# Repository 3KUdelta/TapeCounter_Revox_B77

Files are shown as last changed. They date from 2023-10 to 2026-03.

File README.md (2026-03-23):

# TapeCounter_Revox_B77
Arduino Nano based, digital counter for a Revox B77 Reel-to-Reel with Rewind2Zero function.

# PLEASE SEE NEW VERSION - allthough this version is perfectly running, it will not be further managed or developed. https://github.com/3KUdelta/TapeCounter_Revox_B77_NG

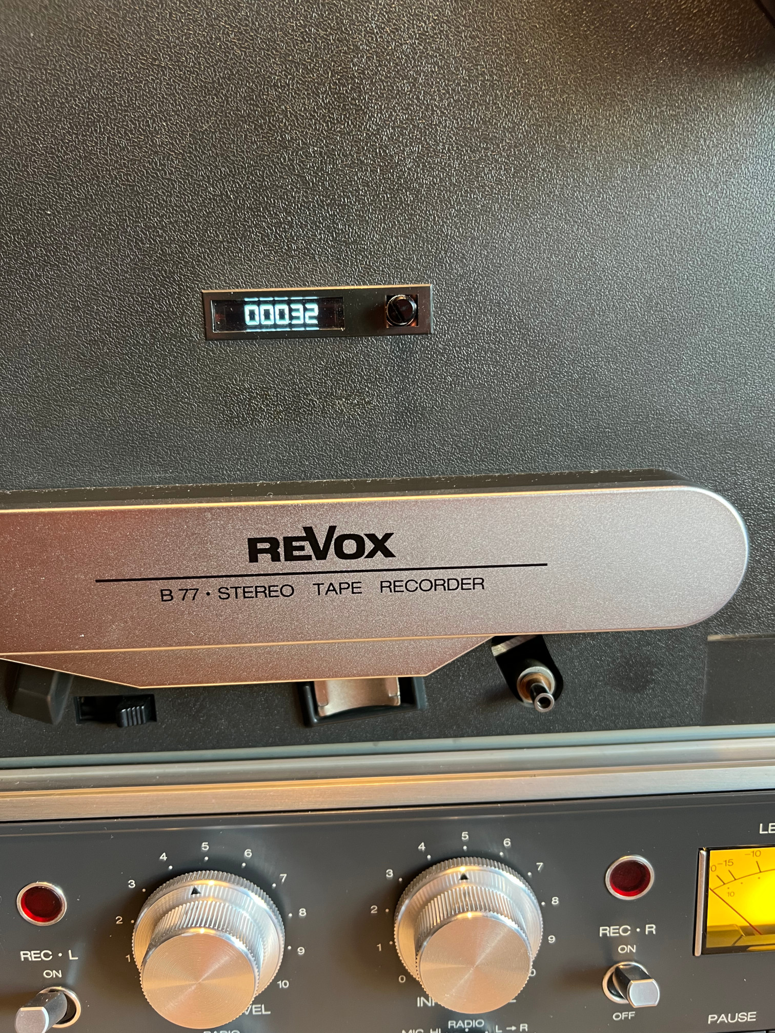
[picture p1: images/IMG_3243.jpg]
(https://github.com/3KUdelta/TapeCounter_Revox_B77)


Original idea & code from https://old-fidelity-forum.de/thread-38940.html
Special thanks to DIYLAB-Bruno, User "Gogosch" and all that have participated - excellent work, Gentlemen!

Version 2.0 stable:

- Click on boot: total running hours
- Click to reset
- Turn to change from counter to meters to seconds (simple conversion - no true seconds)
- Hold to change brightness
- Pause indicator (needs Pause Memory PCB: eBay Mauro200id)
- Auto rewind to 0 on double click (needs relais module)
- 3D files for relais bracket, main board distance bracket and IR Sensor clips are included

Hardware needed:

- 2 HW-006 V1.3 Line Tracker Sensor Modules
- 4 white markers on right spooling motor
- 1 EC12 RE1 360 Degree Rotary Encocer with push button
- 1 0.91 inch OLED module white 128X32
- ~~1 Mini DC-DC 12-24V To 5V 3A Step Down Power Supply Module~~ (edit: unfortunately this causes a very low disturbing noise)
- 1 Mini 230V AC to 5V DC 2A power supply (to get clean discrete power for your arduino & acessories)
- 1 Relay module 2 Channel 5V 12V Relay Module Board Shield with Optocoupler Support High and Low Level Trigger for Arduino 

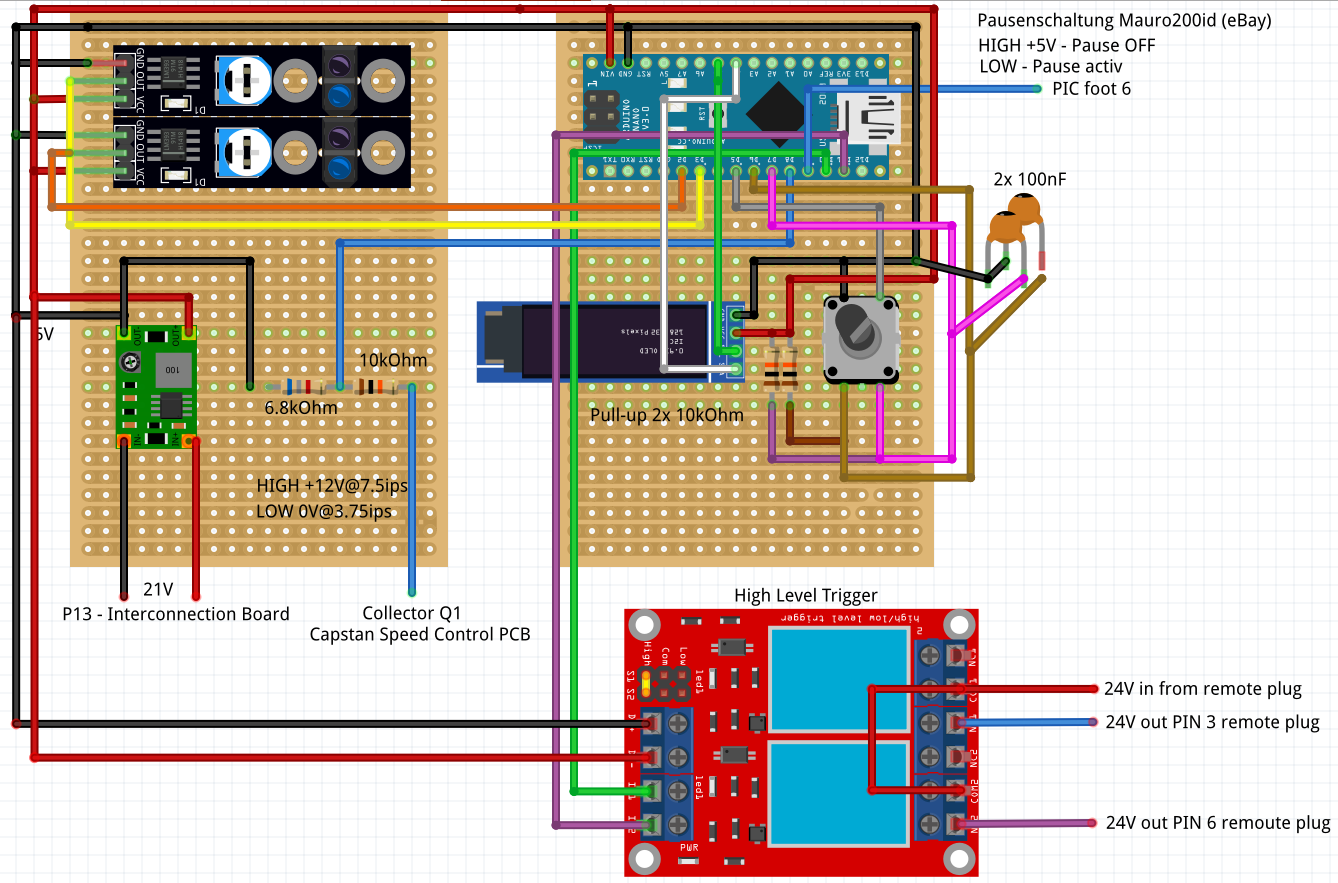
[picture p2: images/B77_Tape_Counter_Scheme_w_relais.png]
(https://github.com/3KUdelta/TapeCounter_Revox_B77)


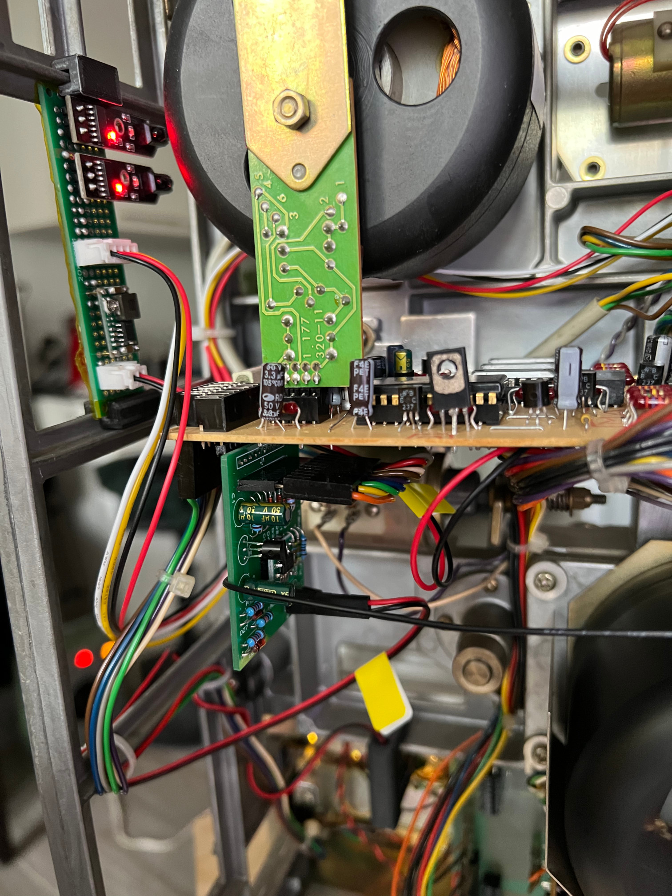
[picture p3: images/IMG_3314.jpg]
(https://github.com/3KUdelta/TapeCounter_Revox_B77)


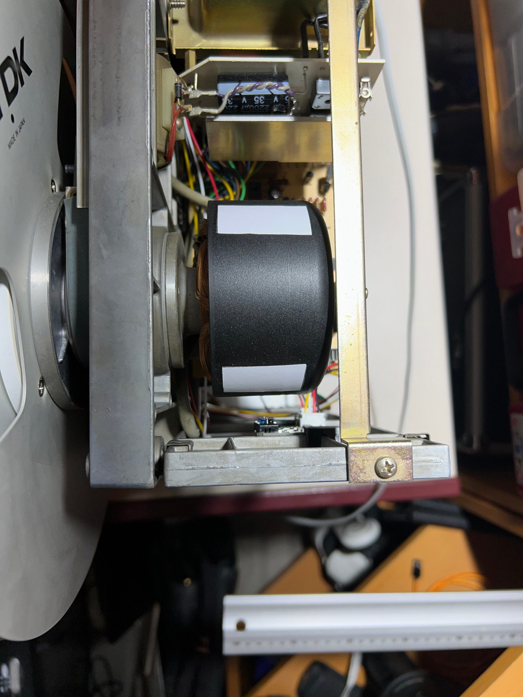
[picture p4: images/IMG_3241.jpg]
(https://github.com/3KUdelta/TapeCounter_Revox_B77)


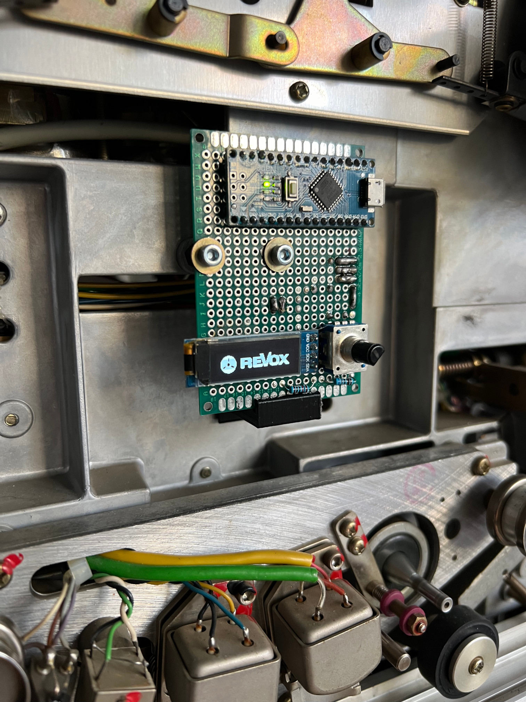
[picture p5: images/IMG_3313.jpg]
(https://github.com/3KUdelta/TapeCounter_Revox_B77)


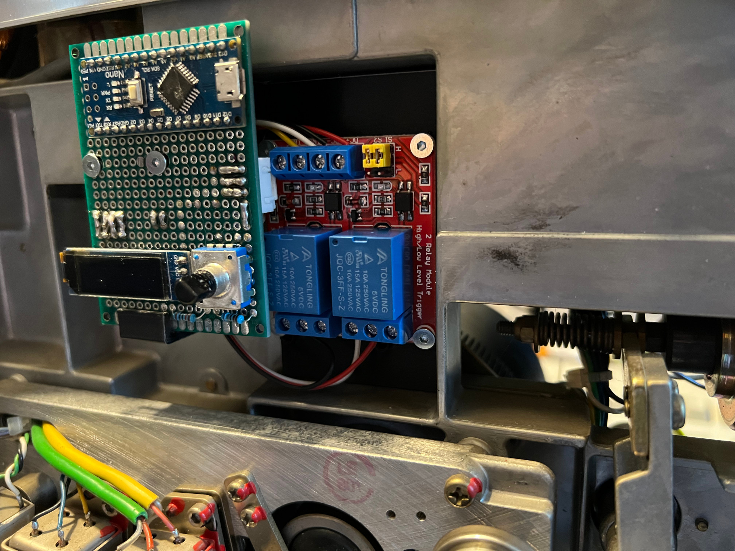
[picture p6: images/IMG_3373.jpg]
(https://github.com/3KUdelta/TapeCounter_Revox_B77)


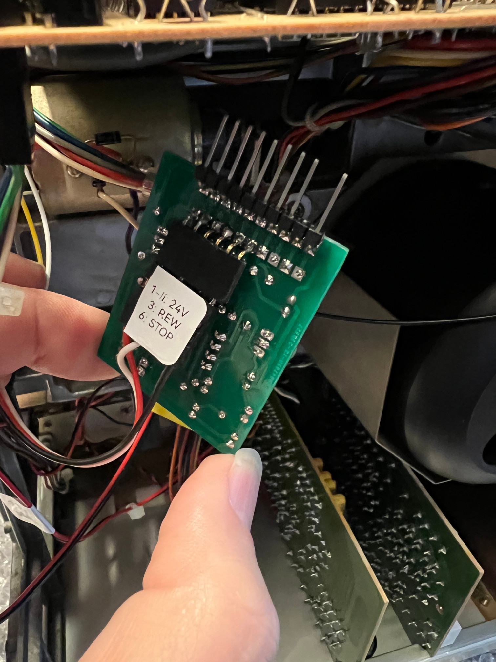
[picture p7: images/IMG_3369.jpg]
(https://github.com/3KUdelta/TapeCounter_Revox_B77)


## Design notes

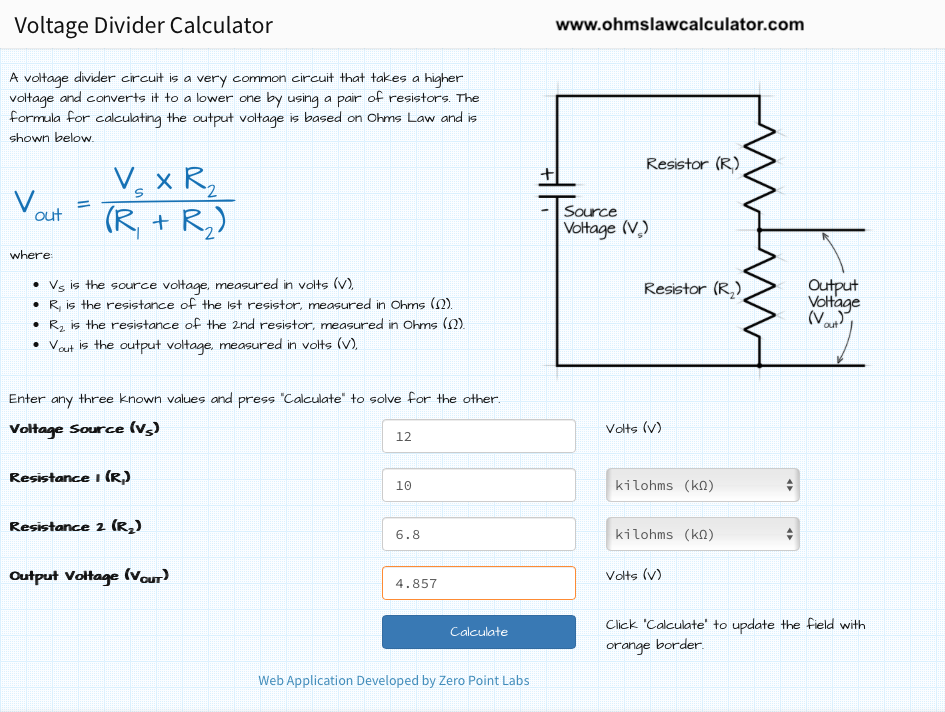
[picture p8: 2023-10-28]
images/B77_voltage_divider_speed_pin.png

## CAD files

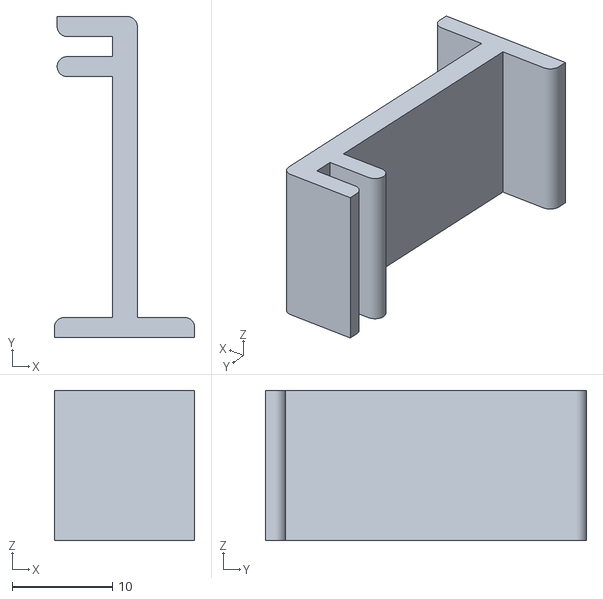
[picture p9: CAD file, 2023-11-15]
3d_STL_files/B77_Abstandshalter.stl
14.0 x 32.0 x 15.0

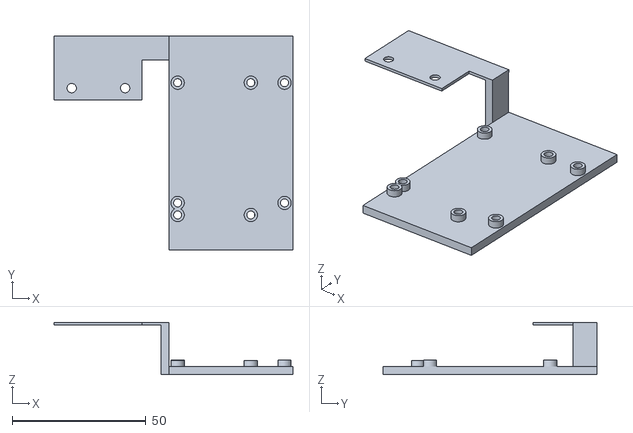
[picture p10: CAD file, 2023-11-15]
3d_STL_files/B77_Relaishalterung.stl
89.4 x 80.0 x 19.6

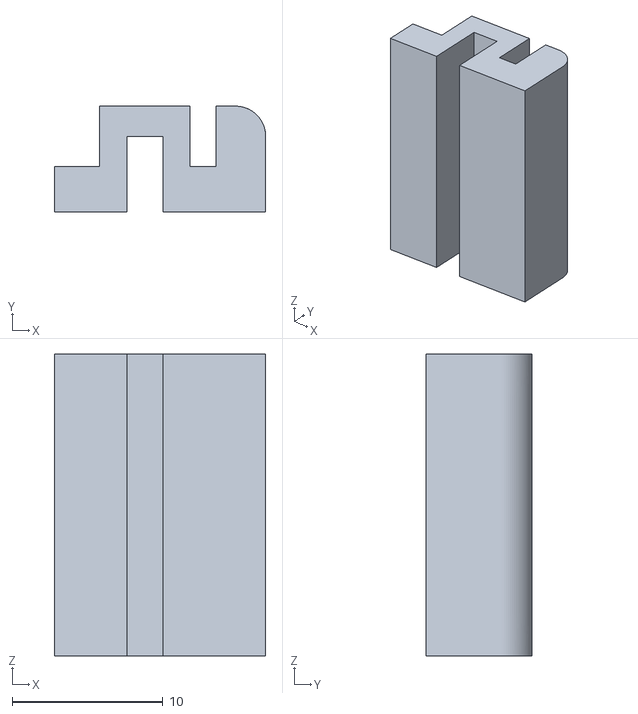
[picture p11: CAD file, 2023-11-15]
3d_STL_files/Bracket_IR_sensor.stl
14.0 x 7.00 x 20.0

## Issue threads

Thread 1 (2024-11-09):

Issue with the project

tommibru, 2024-11-09:
Hello there, we have just tried my dad an I to replicate the system exactly and we aren't being able to get anything to display on the oled.

But when uploading a scratch from the SSD1306 the screen works.

We have tried to troubleshoot but we couldn't get anywhere so far.

Any idea what it could be?

Thanks
-T

3KUdelta, 2024-11-10:
This seems to me like a library problem. Please make sure that you are using exactly this library:
name=SSD1306Ascii
version=1.3.5
author=Bill Greiman <fat16lib@sbcglobal.net>
maintainer=Bill Greiman <fat16lib@sbcglobal.net>
sentence=Text display on small monochrome OLED modules.
paragraph=A basic SSD1306 text only library optimized for minimum memory usage.
category=Display
url=https://github.com/greiman/SSD1306Ascii

Best, Marc

3KUdelta, 2024-11-11:
Hi, the file has been uploaded. It would be helpful if you upload your compilation error messages.
Best, Marc

tommibru, 2024-11-11:
I don't get any compilation errors. From what I can tell the sketch is uploaded correctly.

I will upload with the new file now and test.

-T

tommibru, 2024-11-11:
I tried and no luck, but looking at your images I just realized our display has GND VCC SCL(yours had SDK) SDA

I'm wondering now if that is the issue.

-T

3KUdelta, 2024-11-11:
#define I2C_ADDRESS 0x3C      // I2C display address (0x3C/0x3D, depending on display type)

It could be that your display is using a different address - try using 0x3C. Or if this does not work use an example code to scan your device address for I2C in order to find the correct address of your display.

Else: With a NANO SCL must be connected to A5 and SDA must be A4.

Marc

tommibru, 2024-11-11:
I just used a scanner sketch and confirming it is 0x3C.

tommibru, 2024-11-11:
Uploaded the HelloWorldWire sketch.

This is how it shows.
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

3KUdelta, 2024-11-11:
That's good news. No try the same example but merge the settings from the TapeCounter.

tommibru, 2024-11-11:
Good evening, we did figure it out. We had a batch of nanos that were causing the issue. I loaded on an uno and it worked. Then found an older nano and got it all up and running.

Thank you for the support sir!!

3KUdelta, 2024-11-11:
Happy to hear. Good luck with your project.

Closed 2024-11-23.

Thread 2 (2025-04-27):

Hallo Fehler beim kompalieren

ruebraun, 2025-04-27:
Leider habe ich unterschiedliche Fehler.

Mirt welcher IDE Version wird die Software kompaliert und welche Version sollen die Libs haben?

Danke

3KUdelta, 2025-04-27:
Vielen Dank für Ihre Nachfrage. Bitte kopieren Sie Ihren Fehlercode in Github, dann kann ich Ihnen wahrscheinlich weiterhelfen.

ruebraun, 2025-04-28:
Guten Morgen,

hier der Fehlercode...

Arduino: 1.8.16 (Windows 10), Board: "Arduino Nano, ATmega328P (Old Bootloader)"

`Arduino: 1.8.16 (Windows 10), Board: "Arduino Nano, ATmega328P (Old Bootloader)"

In file included from C:\Users\User\Downloads\TapeCounter_Revox_B77-main\TapeCounter_Revox_B77-main\B77_TapeCounter\B77_TapeCounter.ino:114:0:

C:\Users\User\Documents\Arduino\libraries\Encoder-master/Encoder.h:66:11: error: 'IO_REG_TYPE' does not name a type; did you mean 'MEM_TYPE'?

  volatile IO_REG_TYPE * pin1_register;

           ^~~~~~~~~~~

           MEM_TYPE

C:\Users\User\Documents\Arduino\libraries\Encoder-master/Encoder.h:67:11: error: 'IO_REG_TYPE' does not name a type; did you mean 'MEM_TYPE'?

  volatile IO_REG_TYPE * pin2_register;

           ^~~~~~~~~~~

           MEM_TYPE

C:\Users\User\Documents\Arduino\libraries\Encoder-master/Encoder.h:68:2: error: 'IO_REG_TYPE' does not name a type; did you mean 'MEM_TYPE'?

  IO_REG_TYPE            pin1_bitmask;

  ^~~~~~~~~~~

  MEM_TYPE

C:\Users\User\Documents\Arduino\libraries\Encoder-master/Encoder.h:69:2: error: 'IO_REG_TYPE' does not name a type; did you mean 'MEM_TYPE'?

  IO_REG_TYPE            pin2_bitmask;

  ^~~~~~~~~~~

  MEM_TYPE

C:\Users\User\Documents\Arduino\libraries\Encoder-master/Encoder.h: In member function 'void Encoder::begin(uint8_t, uint8_t)':

C:\Users\User\Documents\Arduino\libraries\Encoder-master/Encoder.h:92:11: error: 'struct Encoder_internal_state_t' has no member named 'pin1_register'

   encoder.pin1_register = PIN_TO_BASEREG(pin1);

           ^~~~~~~~~~~~~

C:\Users\User\Documents\Arduino\libraries\Encoder-master/Encoder.h:93:11: error: 'struct Encoder_internal_state_t' has no member named 'pin1_bitmask'

   encoder.pin1_bitmask = PIN_TO_BITMASK(pin1);

           ^~~~~~~~~~~~

C:\Users\User\Documents\Arduino\libraries\Encoder-master/Encoder.h:94:11: error: 'struct Encoder_internal_state_t' has no member named 'pin2_register'

   encoder.pin2_register = PIN_TO_BASEREG(pin2);

           ^~~~~~~~~~~~~

C:\Users\User\Documents\Arduino\libraries\Encoder-master/Encoder.h:95:11: error: 'struct Encoder_internal_state_t' has no member named 'pin2_bitmask'

   encoder.pin2_bitmask = PIN_TO_BITMASK(pin2);

           ^~~~~~~~~~~~

In file included from C:\Users\User\Documents\Arduino\libraries\Encoder-master/Encoder.h:41:0,

                 from C:\Users\User\Downloads\TapeCounter_Revox_B77-main\TapeCounter_Revox_B77-main\B77_TapeCounter\B77_TapeCounter.ino:114:

C:\Users\User\Documents\Arduino\libraries\Encoder-master/Encoder.h:102:31: error: 'struct Encoder_internal_state_t' has no member named 'pin1_register'

   if (DIRECT_PIN_READ(encoder.pin1_register, encoder.pin1_bitmask)) s |= 1;

                               ^

C:\Users\User\Documents\Arduino\libraries\Encoder-master/utility/direct_pin_read.h:8:46: note: in definition of macro 'DIRECT_PIN_READ'

 #define DIRECT_PIN_READ(base, mask)     (((*(base)) & (mask)) ? 1 : 0)

                                              ^~~~

C:\Users\User\Documents\Arduino\libraries\Encoder-master/Encoder.h:102:54: error: 'struct Encoder_internal_state_t' has no member named 'pin1_bitmask'

   if (DIRECT_PIN_READ(encoder.pin1_register, encoder.pin1_bitmask)) s |= 1;

                                                      ^

C:\Users\User\Documents\Arduino\libraries\Encoder-master/utility/direct_pin_read.h:8:56: note: in definition of macro 'DIRECT_PIN_READ'

 #define DIRECT_PIN_READ(base, mask)     (((*(base)) & (mask)) ? 1 : 0)

                                                        ^~~~

C:\Users\User\Documents\Arduino\libraries\Encoder-master/Encoder.h:103:31: error: 'struct Encoder_internal_state_t' has no member named 'pin2_register'

   if (DIRECT_PIN_READ(encoder.pin2_register, encoder.pin2_bitmask)) s |= 2;

                               ^

C:\Users\User\Documents\Arduino\libraries\Encoder-master/utility/direct_pin_read.h:8:46: note: in definition of macro 'DIRECT_PIN_READ'

 #define DIRECT_PIN_READ(base, mask)     (((*(base)) & (mask)) ? 1 : 0)

                                              ^~~~

C:\Users\User\Documents\Arduino\libraries\Encoder-master/Encoder.h:103:54: error: 'struct Encoder_internal_state_t' has no member named 'pin2_bitmask'

   if (DIRECT_PIN_READ(encoder.pin2_register, encoder.pin2_bitmask)) s |= 2;

                                                      ^

C:\Users\User\Documents\Arduino\libraries\Encoder-master/utility/direct_pin_read.h:8:56: note: in definition of macro 'DIRECT_PIN_READ'

 #define DIRECT_PIN_READ(base, mask)     (((*(base)) & (mask)) ? 1 : 0)

                                                        ^~~~

C:\Users\User\Downloads\TapeCounter_Revox_B77-main\TapeCounter_Revox_B77-main\B77_TapeCounter\B77_TapeCounter.ino: In function 'void setup()':

B77_TapeCounter:288:3: error: 'OverflowCalculation' was not declared in this scope

   OverflowCalculation();

   ^~~~~~~~~~~~~~~~~~~

B77_TapeCounter:290:3: error: 'CalculatingDisplayParameters' was not declared in this scope

   CalculatingDisplayParameters();

   ^~~~~~~~~~~~~~~~~~~~~~~~~~~~

B77_TapeCounter:292:3: error: 'setupTimer1' was not declared in this scope

   setupTimer1();

   ^~~~~~~~~~~

C:\Users\User\Downloads\TapeCounter_Revox_B77-main\TapeCounter_Revox_B77-main\B77_TapeCounter\B77_TapeCounter.ino: In function 'void loop()':

B77_TapeCounter:325:5: error: 'CenterStringAndWrite' was not declared in this scope

     CenterStringAndWrite("PAUSE", 1);

     ^~~~~~~~~~~~~~~~~~~~

B77_TapeCounter:328:5: error: 'RefreshDisplay' was not declared in this scope

     RefreshDisplay(true);

     ^~~~~~~~~~~~~~

C:\Users\User\Downloads\TapeCounter_Revox_B77-main\TapeCounter_Revox_B77-main\B77_TapeCounter\B77_TapeCounter.ino:328:5: note: suggested alternative: 'lockDisplay'

     RefreshDisplay(true);

     ^~~~~~~~~~~~~~

     lockDisplay

B77_TapeCounter:363:5: error: 'CalculatingDisplayParameters' was not declared in this scope

     CalculatingDisplayParameters();

     ^~~~~~~~~~~~~~~~~~~~~~~~~~~~

B77_TapeCounter:366:23: error: 'RefreshDisplay' was not declared in this scope

     if (!lockDisplay) RefreshDisplay(false);

                       ^~~~~~~~~~~~~~

C:\Users\User\Downloads\TapeCounter_Revox_B77-main\TapeCounter_Revox_B77-main\B77_TapeCounter\B77_TapeCounter.ino:366:23: note: suggested alternative: 'lockDisplay'

     if (!lockDisplay) RefreshDisplay(false);

                       ^~~~~~~~~~~~~~

                       lockDisplay

C:\Users\User\Downloads\TapeCounter_Revox_B77-main\TapeCounter_Revox_B77-main\B77_TapeCounter\B77_TapeCounter.ino: In function 'void EncoderRotated(bool)':

B77_TapeCounter:468:3: error: 'RefreshDisplay' was not declared in this scope

   RefreshDisplay(true);

   ^~~~~~~~~~~~~~

C:\Users\User\Downloads\TapeCounter_Revox_B77-main\TapeCounter_Revox_B77-main\B77_TapeCounter\B77_TapeCounter.ino:468:3: note: suggested alternative: 'lockDisplay'

   RefreshDisplay(true);

   ^~~~~~~~~~~~~~

   lockDisplay

C:\Users\User\Downloads\TapeCounter_Revox_B77-main\TapeCounter_Revox_B77-main\B77_TapeCounter\B77_TapeCounter.ino: In function 'void ButtonClick()':

B77_TapeCounter:486:3: error: 'RefreshDisplay' was not declared in this scope

   RefreshDisplay(true);

   ^~~~~~~~~~~~~~

C:\Users\User\Downloads\TapeCounter_Revox_B77-main\TapeCounter_Revox_B77-main\B77_TapeCounter\B77_TapeCounter.ino:486:3: note: suggested alternative: 'lockDisplay'

   RefreshDisplay(true);

   ^~~~~~~~~~~~~~

   lockDisplay

C:\Users\User\Downloads\TapeCounter_Revox_B77-main\TapeCounter_Revox_B77-main\B77_TapeCounter\B77_TapeCounter.ino: In function 'void ButtonLongPressStop()':

B77_TapeCounter:585:3: error: 'RefreshDisplay' was not declared in this scope

   RefreshDisplay(true);

   ^~~~~~~~~~~~~~

C:\Users\User\Downloads\TapeCounter_Revox_B77-main\TapeCounter_Revox_B77-main\B77_TapeCounter\B77_TapeCounter.ino:585:3: note: suggested alternative: 'lockDisplay'

   RefreshDisplay(true);

   ^~~~~~~~~~~~~~

   lockDisplay

C:\Users\User\Downloads\TapeCounter_Revox_B77-main\TapeCounter_Revox_B77-main\B77_TapeCounter\B77_TapeCounter.ino: At global scope:

B77_TapeCounter:587:1: error: expected unqualified-id before '{' token

 {

 ^

exit status 1

'OverflowCalculation' was not declared in this scope

Dieser Bericht wäre detaillierter, wenn die Option
"Ausführliche Ausgabe während der Kompilierung"
in Datei -> Voreinstellungen aktiviert wäre.
`

ruebraun, 2025-04-28:
Hallo,
es scheint etwas mit der IDE-Version und den Liberay Version des Encoders zu tun zu haben.
Danke füür deine Hilfe.

-Arduino IDE 1.8.3
-Encoder 1.4.3

`Arduino: 1.8.3 (Windows 10), Board: "Arduino Nano, ATmega328"
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
3KUdelta, 2025-04-28:
Hallo Rüdiger,

der Code kompiliert unter 1.8.19 und 2.3.6 bei mir immer noch nach all der Zeit fehlerfrei durch.

1.) Encoder Library
name=Encoder
version=1.4.4
author=Paul Stoffregen

Die Library heisst bei Dir encoder-master. Das zeigt mir, dass Du das von einem Git runtergeladen hast. Bitte nimm die "offizielle" Library innerhalb von Arduino.

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

2.) Die Files logo_mst1.h, tapecounter_16x24.h, tapecounter_21x32.h müssen im gleichen Verzeichnis wie B77_TapeCounter liegen und in der IDE oben als Reiter erscheinen.

Ich hoffe, damit klappt es.

ruebraun, 2025-04-28:
Okay, danke das wars

Wie ich vermutet hatte die Versin stimmte nicht. Es muss V 1.4.4 sein
Die Erweiterung master ist unerheblich.

Mir sind die Relais nicht ganz klar, kannst du mir da noch einen Tip geben?

MfG

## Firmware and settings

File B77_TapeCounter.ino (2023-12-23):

/*
  __ __|                     ___|                       |                    __ ) ___  | ___  |
    |   _` |  __ \    _ \  |       _ \   |   |  __ \   __|   _ \   __|      __ \     /      /
    |  (   |  |   |   __/  |      (   |  |   |  |   |  |     __/  |         |   |   /      /
   _| \__,_|  .__/  \___| \____| \___/  \__,_| _|  _| \__| \___| _|        ____/  _/     _/
             _|

   ARDUINO OLED TAPE COUNTER FOR REVOX B77 REEL-TO-REEL MACHINES
   based on
   Copyright (C) 2020 by DIYLAB, v0.99-rc1, 30.05.2020
   Version 2.0, October 2023 modified by Marc Stähli
   ~~~~~~~~~~~~~~~~~~~~~~~~~~~~~~~~~~~~~~~~~~~~~~~~~~~~~~~~~~~~~~~~~~~~~~~~~~~~~~~~~~~~~~~~~~~~~~~~
   This Software is free software: you can redistribute it and/or modify
   it under the terms of the GNU General Public License as published by
   the Free Software Foundation, either version 3 of the License, or
   (at your option) any later version.

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
   You should have received a copy of the GNU General Public License
   along with the Arduino SSD1306Ascii Library.  If not, see
   <http://www.gnu.org/licenses/>.

   ################################################################################################
   # Many thanks for the great interest of the colleagues from the                                #
   # 'Old Fidelity Forum' https://old-fidelity-forum.de/thread-38940.html                         #
   # and https://old-fidelity-forum.de/thread-38716.html                                          #
   # and especially for the fantastic help of the user 'gogosch'!                                 #
   ################################################################################################

   Used libraries
   --------------
   Arduino OneButton Library: <https://github.com/mathertel/OneButton>
   SSD1306Ascii: <https://github.com/greiman/SSD1306Ascii>

   ###############################################################################################

   Update & Modifications in October 23 for B77:

   All modifications done especially for a B77 MKI - HiFi Labor rebuild
   hifilabor.ch, Marc Stähli - Vielen Dank für die tolle und solide Arbeit!

   Using an Arduino Nano with igital pins on 5V (!ESP pins are 3.3V!)
   Using two HW-006 V.1.3 Line Tracker Sensor Modules and two white segmens on right spooling
   motor feeding Pin 2 and 3 at the Nano for interrupts
   Using one 360 Degree Rotary Encoder EC12 RE1 for button push and turning

   - slimmed down code for single use of B77 (MKI) and only one font
   - Transistor Q1 on Capstan Speed Control PCP (Collector@Q1) delivers 12 V at 7.5 ips and
     0 V at 3.75 ips, fed into SPEED_Pin via voltage divider R1 10 KOhm, R2 6.8 KOhm = 4.8 V
   - added display offset for x and y for fitting purposes
   - added rotary encoder/switch combination
      - knob rotation lets you switch between counter, meter and seconds
      - double click automatically rewinds to counter zero
   - found a compromize with "real-time" settings measuring at the right reel
   - hooked Nano Pin (9) to Pause PCB from Mauro200id - ebay (PIC foot 6  --> is low on pause)fj
   - added rewind2zero functionality  - 2 relais hooked to Nano pin 10 and 11 controlling
     the connection of 24V from the remote control pins to pin 3 and 6 in order to do rewind and 
     stop.
*/

//////////////////////////////////////////////////////////////////////////////////////////////////
// USER CONFIG SECTION (please only edit here!)                                                 //
//////////////////////////////////////////////////////////////////////////////////////////////////

// Software configuration:
#define SW_VERSION 2.0       // Current version of the software
#define HELLO_LOGO true      // Show logo picture.
#define HELLO_TEXT false     // Show welcoming text (search for 'welcome helloText').
#define HELLO_TIMEOUT 3000   // The display duration of the greeting in ms.
#define BRIGHTNESS 128       // Display brightness (0 to 255).
#define FLIPDISPLAY true     // Set the display to normal (false) oder 180 degree mode (true).
#define INVERTDISPLAY false  // Set inverted display (true) or normal dispalay (false).
#define UNSIGN false         // Minus sign (true: sign not shown, false: sign shown).
#define DIGITS_MINUTES 3     // Digits for the minute display in realtime mode (2 or 3).
#define DIGITS_COUNTER 5     // Number of digits for normal counter (FontSize1: 4, 5 or 6 - FontSize2: 4 or 5).
#define PULSES_COUNTER 2     // Number of pulses for one count in counter mode (1 to 255).
#define OPHOURSOFFSET 0      // Offset for operating hours counter in seconds. Example: 1261440000 = 40 YEARS ;o)
#define OLED_X_OFFSET 2      // Offset for shifting the OLED output in X direction (e.g. + 1 = shift 1 pixel to the right)
#define OLED_Y_OFFSET 0      // Offset for shifting the OLED output in Y direction (e.g. -1 = shift 8 pixels up)

// Meter and realtime preferences by gogosch ~~~~~~~~~~~~~~~~~~~~~~~~~~~~~~~~~~~~~~~~~~~~~~~~~~~~~~
#define SPEEDHIGH 381.0    // Highest belt speed 15" in mm/s
#define SPEEDMIDDLE 190.5  // Middle  belt speed 7,5" in mm/s
#define SPEEDLOW 95.25     // Lowest  belt speed 3,75" in mm/s
#define NUMSEGS 4          // Segments on the tape reel
#define SCOPE 580          // Ment to be circumference, but more a trimming value

// Further adjustments (only  change if you know what you are doing!).~~~~~~~~~~~~~~~~~~~~~~~~~~~~~~
#define SENSOR_A 3            // INPUT PIN (Sensor-A) 'INT0'.
#define SENSOR_B 2            // INPUT PIN (Sensor-B)	'INT1'.
#define BUTTON 5              // INPUT PIN (RESET-Button).
#define ROTARY_A 6            // Rotary Switch A signal in
#define ROTARY_B 7            // Rotary Switch B signal in
#define SPEED_PIN 8           // Speed Input pin after Voltage Divider (high = 7.5 ips, low = 3.75 ips)
#define LED 13                // Onboard LED.
#define EEPROM_MODE 10        // EEPROM address for mode.
#define EEPROM_BRIGHTNESS 20  // EEPROM address for brightness.
#define EEPROM_COUNTER 100    // EEPROM address for counter data.
#define EEPROM_METER 200      // EEPROM address for meter data.
#define EEPROM_REALTIME 300   // EEPROM address for realtime data.
#define EEPROM_OPHOURS 400    // EEPROM address for operating hour counter data.
#define I2C_ADDRESS 0x3C      // I2C display address (0x3C/0x3D, depending on display type).
#define PAUSE_PIN 9           // Pin goes low when PAUSE is engaged
#define REW_PIN 10            // Triggers Relais to Rewind
#define STOP_PIN 11           // Triggers Relais to Stop

//////////////////////////////////////////////////////////////////////////////////////////////////
#define ENCODER_DO_NOT_USE_INTERRUPTS
#include <OneButton.h>
#include <Encoder.h>
#include <EEPROM.h>
#include <SSD1306Ascii.h>
#include "SSD1306AsciiWire.h"
#include "tapecounter_16x24.h"
#include "tapecounter_21x32.h"

#if HELLO_LOGO
#include "logo_mst1.h"
#endif

// Time constants.
#define SECS_PER_MIN (60UL)
#define SECS_PER_HOUR (3600UL)
#define SECS_PER_DAY (SECS_PER_HOUR * 24L)

// Macros for getting elapsed time.
#define numberOfSeconds(_time_) (_time_ % SECS_PER_MIN)
#define numberOfMinutes(_time_) ((_time_ / SECS_PER_MIN) % SECS_PER_MIN)
#define numberOfMinutesEx(_time_) (_time_ / SECS_PER_MIN)
#define numberOfHours(_time_) ((_time_ % SECS_PER_DAY) / SECS_PER_HOUR)
#define elapsedDays(_time_) (_time_ / SECS_PER_DAY)

OneButton btn(BUTTON, true, true);
Encoder rotaryEncoder(ROTARY_A, ROTARY_B);

SSD1306AsciiWire oled;

// Struct for welcome message.
typedef struct
{
  char* msg;
  byte col;
  byte row;
} welcome;

/**************************************************************************/
/*!
	Here you define the welcome text. A maximum of 2 lines is possible.
	Syntax: Message, column (0 to 128), row (1 or 2).
	If a line is not used, it is commented out.
*/
/**************************************************************************/
welcome helloText[2] = {
  /*Line1*/ { "HiFiLabor.ch", 52 + OLED_X_OFFSET, 1 },
  /*Line2*/ { "COUNTER 2.0", 52 + OLED_X_OFFSET, 2 },
};

volatile uint32_t operatingHoursCounter, saveCounter, intervalA, intervalB, intervalC, intervalD, intervalE, intervalF, intervalM;
volatile bool ledTrigger, speedTrigger, pauseTrigger, lockDisplay, pastPinA, pinA;
volatile byte mode, loopCounter;
volatile byte brightness = BRIGHTNESS;
/////////////////////////////// Rew2Zero VARS //////////////////////////////
String movement;
bool rewindToZero = false;
long counterStart, prevCounter;
/////////////////////////////// COUNTER VARS ///////////////////////////////
long counter, pastCounter, longCounterSeconds, pastLongCounterSeconds;
float counterMeters, pastCounterMeters, counterSeconds, pastCounterSeconds, secsPerPulse, mmPerPulse, speedActual, pastSpeedActual;
float numSegs = NUMSEGS;
float scope = SCOPE;
////////////////////////////////////////////////////////////////////////////

/**************************************************************************/
/*!
   @brief   Setup
*/
/**************************************************************************/
void setup() {
  Serial.begin(9600);
  // Set inputs.
  pinMode(SENSOR_A, INPUT);
  pinMode(SENSOR_B, INPUT);
  pinMode(SPEED_PIN, INPUT);
  pinMode(PAUSE_PIN, INPUT);
  // Set outputs.
  pinMode(LED, OUTPUT);
  pinMode(REW_PIN, OUTPUT);
  pinMode(STOP_PIN, OUTPUT);

  // Set pinchange interrupts.
  attachInterrupt(0, CheckState, CHANGE);
  attachInterrupt(1, CheckState, CHANGE);
  // Link the button functions.
  btn.attachClick(ButtonClick);
  btn.attachDoubleClick(ButtonDoubleClick);
  btn.attachLongPressStart(ButtonLongPressStart);
  btn.attachLongPressStop(ButtonLongPressStop);
  btn.attachDuringLongPress(ButtonLongPress);
  // Initialize display.
  oled.begin(&Adafruit128x32, I2C_ADDRESS);
  // Set display brightness.
  oled.setContrast(BRIGHTNESS);
  // Set display to normal (false) oder 180 degree mode (true).
  oled.displayRemap(FLIPDISPLAY);
  // Set inverted display (true) or normal dispalay (false).
  oled.invertDisplay(INVERTDISPLAY);
  // Clear the display and set the cursor to (0,0).
  oled.clear();

#if HELLO_LOGO
  // For a 128x32 image.
  byte r = 0;  // Start row
  byte c = 0;  // Start col
  int a = 0;   // Position in array

  for (byte b = 0; b < 4; b++) {
    oled.setCursor(c, (r + b));
    for (byte i = 0; i < 128; i++) {
      oled.ssd1306WriteRam(pgm_read_byte(&logo[a]));
      a++;
    }
  }
#endif

#if HELLO_TEXT
  // Set message font, cursor and text.
  oled.setFont(utf8font10x16);
  for (size_t i = 0; i < (sizeof(helloText) / sizeof(helloText[0])); i++) {
    oled.setCursor(helloText[i].col + OLED_X_OFFSET, (helloText[i].row == 1) ? 0 : 2);
    oled.print(helloText[i].msg);
  }
#endif

#if HELLO_LOGO || HELLO_TEXT
  // Display specific time.
  delay(HELLO_TIMEOUT);

  // Clear the display and set the cursor to (0,0).
  oled.clear();
#endif

  // Get last realtime data from the EEPROM.
  EEPROM.get(EEPROM_OPHOURS, operatingHoursCounter);

  // Show the operating hours.
  if (digitalRead(BUTTON) == LOW) {
    char opHoursBuffer[48];
    opHoursSecondsToString(opHoursBuffer, operatingHoursCounter + OPHOURSOFFSET);
    oled.setFont(utf8font10x16);
    oled.setCursor(0 + OLED_X_OFFSET, 0 + OLED_Y_OFFSET);
    oled.print(opHoursBuffer);
    // Waiting for release the button.
    while (digitalRead(BUTTON) == LOW) {}
    oled.clear();
  }
  // Initialize font size
  oled.setFont(tapecounter_16x24);
  // Initialization of the virgin EEPROM at the very first start.
  if (EEPROM.read(1000) == 255 && EEPROM.read(1001) == 255) {
    // Successful deflowered ;o)
    EEPROM.write(1000, 0);
    EEPROM.write(1001, 0);
    // Initialize EEPROM.
    EEPROM.write(EEPROM_MODE, 0);
    EEPROM.write(EEPROM_BRIGHTNESS, BRIGHTNESS);
    SaveCounter();
  }

  // Get last mode from the EEPROM.
  mode = EEPROM.read(EEPROM_MODE);
  // Get last brightness from the EEPROM.
  brightness = EEPROM.read(EEPROM_BRIGHTNESS);
  // Get last counter data from the EEPROM.
  EEPROM.get(EEPROM_COUNTER, counter);
  // Get last meter data from the EEPROM.
  EEPROM.get(EEPROM_METER, counterMeters);
  // Get last realtime data from the EEPROM.
  EEPROM.get(EEPROM_REALTIME, counterSeconds);
  // Counter overflow calculation.
  OverflowCalculation();
  // Calculation of the display parameters for realtime and counter.
  CalculatingDisplayParameters();
  // Initialize timer1 for one second pulses.
  setupTimer1();
}

/**************************************************************************/
/*!
   @brief   MainLoop
*/
/**************************************************************************/

long encPos = rotaryEncoder.read();

void loop() {
  // Watching the push button.
  btn.tick();

  // Watching the encoder
  long newPos = rotaryEncoder.read();
  if (newPos != encPos) {
    if (newPos % 4 == 0) {
      if (newPos > encPos) {
        EncoderRotated(1);  // cw
        encPos = newPos;
      }
      if (newPos < encPos) {
        EncoderRotated(0);  // ccw
        encPos = newPos;
      }
    }
  }

  // Watching the pause button
  if (digitalRead(PAUSE_PIN) == LOW && pauseTrigger == false) {
    oled.clear();
    CenterStringAndWrite("PAUSE", 1);
    pauseTrigger = true;
  } else if (digitalRead(PAUSE_PIN) == HIGH && !lockDisplay) {
    RefreshDisplay(true);
    pauseTrigger = false;
  }

  // Detect movement
  if (millis() > intervalM + 500) {
    intervalM = millis();
    if (prevCounter == counter) {
      movement = "still";
    } else {
      movement = "runs";
    }
    prevCounter = counter;
  }

  // Rewind to zero procedure
  if (rewindToZero && counter > 0) {
    if (movement == "still") {
      counterStart = counter;
      doRewind();
    }
    if (counter == 100 && counterStart != counter) doStop();
    if (counter == 40 && counterStart != counter) doStop();
    if (counter == 10 && counterStart != counter) doStop();
    if (counter == 1) {
      doStop();
      rewindToZero = false;
    }
  }

  // This section is executed every 30ms.
  if (millis() > intervalA + 30) {
    intervalA = millis();

    // Calculation of the display parameters for realtime and counter.
    CalculatingDisplayParameters();

    // Refresh display if no locked.
    if (!lockDisplay) RefreshDisplay(false);
  }

  // Turn onboard LED off.
  if (ledTrigger && (millis() - intervalC > 500)) {
    ledTrigger = false;
    digitalWrite(LED, LOW);
  }

  // Reset speeddisplay.
  if (speedTrigger && (millis() - intervalD > 2000)) {
    speedTrigger = false;

    // Was the display locked from the previous speed display?
    if (lockDisplay) {
      // Clear the display and set the cursor to (0,0).
      oled.clear();
      // Releases the display.
      lockDisplay = false;
      // Reload the pause display monoflop
      pauseTrigger = false;
    }
  }

  // Save current counter data.
  if (saveCounter == 4) {
    saveCounter++;
    // Trigger the onboard LED monoflop.
    ledTrigger = true;
    intervalC = millis();
    // Turn onboard LED on.
    digitalWrite(LED, HIGH);
    // Save current counter data.
    SaveCounter();
  }
}
/**************************************************************************/
/*!
   @brief   Helper function: Trigger the STOP button
*/
/**************************************************************************/
void doStop() {
  if (millis() > intervalF + 250) {  // avoiding double-triggering
    intervalF = millis();
    digitalWrite(STOP_PIN, HIGH);
    delay(10);
    digitalWrite(STOP_PIN, LOW);
  }
}

/**************************************************************************/
/*!
   @brief   Helper function: Trigger the REWIND button
*/
/**************************************************************************/
void doRewind() {
  if (millis() > intervalB + 1500) {  // avoiding double-triggering
    intervalB = millis();
    digitalWrite(REW_PIN, HIGH);
    delay(10);
    digitalWrite(REW_PIN, LOW);
  }
}

/**************************************************************************/
/*!
   @brief   Save counter data to EEPROM.
*/
/**************************************************************************/
void SaveCounter() {
  // Write counter data to EEPROM.
  EEPROM.put(EEPROM_COUNTER, counter);
  // Write meter data to EEPROM.
  EEPROM.put(EEPROM_METER, counterMeters);
  // Write realtime data to EEPROM.
  EEPROM.put(EEPROM_REALTIME, counterSeconds);
  // Write operating hours data to EEPROM.
  EEPROM.put(EEPROM_OPHOURS, operatingHoursCounter);
}

/**************************************************************************/
/*!
   @brief   This function will be called when encoder turned
            sense_up is true
*/
/**************************************************************************/
void EncoderRotated(bool upsense) {
  if (upsense) {
    mode++;
    if (mode > 2)
      mode = 0;
  }
  if (!upsense) {
    mode--;
    if (mode == 255)  // because mode is defined as a byte
      mode = 2;
  }
  // Save current mode to the EEPROM.
  EEPROM.update(EEPROM_MODE, mode);

  oled.clear();
  // Refresh display .
  RefreshDisplay(true);
}

/**************************************************************************/
/*!
   @brief   This function will be called when the button was pressed 1 time.
*/
/**************************************************************************/
void ButtonClick() {
  // Resetting all counters.
  counter = 0;
  counterMeters = 0;
  counterSeconds = 0;
  // Save current counter data.
  SaveCounter();
  // Clear the display and set the cursor to (0,0).
  oled.clear();
  // Refresh display .
  RefreshDisplay(true);
}

/**************************************************************************/
/*!
   @brief   This function will be called when the button
			was pressed 2 times in a short timeframe. Initiates the rewind to zero
      procedure in setting the flag to true
*/
/**************************************************************************/
void ButtonDoubleClick() {
  if (counter > 0) {
    rewindToZero = true;
    movement = "still";  // trick the procedure to start rewinding
  }
}
/**************************************************************************/
/*!
   @brief   This function will be called often,
			while the button is pressed for a long time.
*/
/**************************************************************************/
void ButtonLongPress() {
  // This section is executed every 300ms.
  if (millis() > intervalE + 300) {
    intervalE = millis();

    // The brightness is adjusted in 16 steps.
    brightness++;
    if (brightness > 16)
      brightness = 0;

    // Charbuffer for indicator.
    char buffer[16];
    // Set cursor to right side in line 2.
    oled.setCursor(75 + OLED_X_OFFSET, 2 + OLED_Y_OFFSET);

    // Brightness indicator left and right side.
    for (size_t i = 0; i < brightness; i++) {
      // Left side: set indicator.
      buffer[i] = 133;  // Indicator char.
    }
    for (size_t i = brightness; i < 16; i++) {
      // Right side: clear indicator.
      buffer[i] = 32;  // Space char.
    }

    // Print the buffer on display.
    oled.print(buffer);
    // Setting the brightness * 16 (0 to 256).
    oled.setContrast(brightness * 16);
  }
}

/**************************************************************************/
/*!
   @brief   This function will be called once, when the button is
			pressed for a long time.
*/
/**************************************************************************/
void ButtonLongPressStart() {
  // Lock the display for further output.
  lockDisplay = true;
  // Set font for indicator.
  oled.setFont(utf8font10x16);
  // Clear the display and set the cursor to (0,0).
  oled.clear();
  // Set cursor to left side in line 2.
  oled.setCursor(0 + OLED_X_OFFSET, 2 + OLED_Y_OFFSET);
  // Write message on left side.
  oled.println("BRIGHTNESS:");
}

/**************************************************************************/
/*!
   @brief   This function will be called once, when the button is
			released after beeing pressed for a long time.
*/
/**************************************************************************/
void ButtonLongPressStop() {
  // Save current brightness to the EEPROM.
  EEPROM.update(EEPROM_BRIGHTNESS, brightness);

  // BlingBling ;o)
  for (size_t i = 0; i < 2; i++) {
    oled.setCursor(75 + OLED_X_OFFSET, 2 + OLED_Y_OFFSET);
    oled.print("STORED            ");
    delay(250);
    oled.setCursor(75 + OLED_X_OFFSET, 2 + OLED_Y_OFFSET);
    oled.print("                  ");
    delay(250);
  }
  // Reset Font size
  oled.setFont(tapecounter_16x24);
  // Clear the display and set the cursor to (0,0).
  oled.clear();
  // Releases the display.
  lockDisplay = false;
  // Refresh display .
  RefreshDisplay(true);
}

/**************************************************************************/
/*!
   @brief   Refresh display by different value or forced.
*/
/**************************************************************************/
void RefreshDisplay(boolean force) {
  // Converts float seconds to long.
  longCounterSeconds = (long)counterSeconds;

  // Counter overflow calculation.
  OverflowCalculation();

  // The refresh of the display is forced.
  if (force) {
    // Counter
    if (mode == 0) {
      WriteOled(counter);
    }
    // Meter
    else if (mode == 1) {
      WriteOled(counterMeters);
    }
    // Realtime
    else if (mode == 2) {
      WriteOledRealTime(longCounterSeconds);
    }
  }
  // Only refresh if there is a different value.
  else {
    // Counter
    if (mode == 0 && counter != pastCounter) {
      pastCounter = counter;
      WriteOled(counter);
    }
    // Meter
    else if (mode == 1 && counterMeters != pastCounterMeters) {
      pastCounterMeters = counterMeters;
      WriteOled(counterMeters);
    }
    // Realtime
    else if (mode == 2 && longCounterSeconds != pastLongCounterSeconds) {
      pastLongCounterSeconds = longCounterSeconds;
      WriteOledRealTime(longCounterSeconds);
    }
  }
}
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
